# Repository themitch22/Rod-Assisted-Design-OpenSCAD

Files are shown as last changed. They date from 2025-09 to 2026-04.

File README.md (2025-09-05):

Customizable modular connector system for dowel rods, pipes, and tubes!

This OpenSCAD model was created to construct anything from readily-available and affordable materials such as wooden dowels, PVC pipe, electrical conduit, drinking straws, etc. 

I spent a lot of time developing this OpenSCAD model, if you found this useful and would like to support me, I am accepting tips Ko-Fi tips: https://ko-fi.com/mitch3d

There are 4 types of pieces that can be created:
Connector

The connector can be customized to have a central leg, you add the number of connecting legs you need, adjust the vertical and horizontal angles, and select the diameter, thickness, rib, and screw options. There are added parameters to flatten the top and bottom of the legs to make printing easier, and have a flat side to lay shelving or panels on, and teardrops are optional to further reduce overhangs to make printing easy. Included is a option to add stoppers inside the legs to prevent the rods from slipping through the center. From my testing, the flat and positive angles can all be printed without support. 

Spacer/Panel Mount:
This piece can either be used as a spacer which you can glue to a shelf or panel, or add your own connection type using a boolean geometry. The tab option you can leave blank or enable screws which adds a single centered screw which you can mount to a plywood shelf or ziptie to foamcore board. There is also a skadis option which will add a Ikea Skadis compatible hook either vertically or horizontally. This could be used to make shelves for Skadis walls, or create tape roll holders using dowels. 

Cross Connector:
For potential structure cross bracing, there is a cross connector option. Select an angle and leg length, adjust the screw parameters, This might be useful to create a side or top reinforcement to prevent sheer forces on a structure. 

End Cap/Foot:
The rough edges of a dowel or pipe might be sharp so there is an end cap option. The end cap can also be a foot if you are making shelving to prevent damage to flooring. You could customize this further to add adjustable feet or merge with other models.
Customizing with OpenSCAD

Download the latest version of OpenSCAD 

Install for your system and open the .scad file provided. By default the Customizer panel should be shown next to the preview panel. When you enter a parameter and press enter or tab, it will automatically update the preview. 

    Select the type of connector you need. The default is 1 - connector. 
    Find out your dowel or tube OD, you should get an average diameter with calipers for a tight fit but not too tight. Screws will hold the rods in place, but any play in the connection will cause stress. Add about 0.1-0.2mm of tolerance for extrusion or printer inconsistency, layer squish, or material shrinkage.
     You will need to figure out the number of legs needed and their horizontal or vertical angle. Most features only work with a 0 degree flat vertical angle, but the horizontal angle can be adjusted to suit your needs. If the horizontal angle and number of legs exceed 360 degrees, it will evenly adjust horizontal angle to fit the number of legs around the center leg. 
    Adjust the leg length, center leg length, thickness, rid reinforcement, and chamfer to desired proportions. 
    Decide if you want screws and enable them, and pick either countersink or counterbore so the screw doesn't stick out (unless desired). Then the other parameters including screw angle, which you should adjust to prevent accessibility and geometry issues with interference.
    When you are ready, press Render (F6) first. Then you can Save to STL.

Considerations

Use at your own risk!

3D printed parts, dowels, or tubing are widely variable, you should test your structures first before relying on them to hold any loads. 

Do not trust this to hold anything or anyone you care about. While I'd love to see this be used to make furniture, it should be heavily reinforced with the length of the rod in direct compression to the ground, not in direction of tensile or sheer stresses. Remember to have the sheer strength perpendicular to the layers not parallel along layers. 

PLA while rigid, can creep over time, PETG, ABS, ASA, and CF reinforced filaments are more likely to hold up over time. The material used in the pictures is ASA.

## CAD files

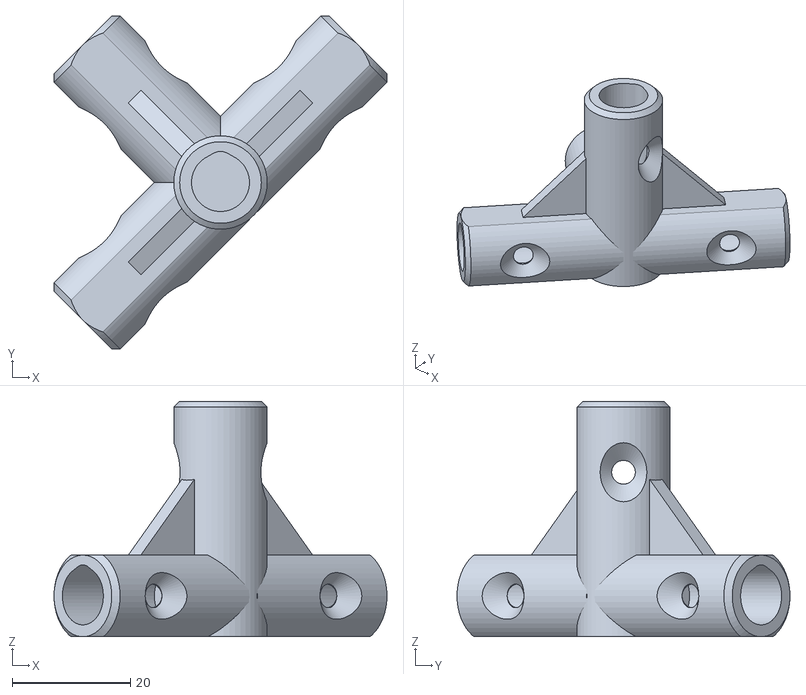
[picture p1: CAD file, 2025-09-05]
3-8th 4-way connector #8 cs screw flat 90 degree.stl
56.3 x 56.3 x 39.8

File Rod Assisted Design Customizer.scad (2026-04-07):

//Dowel Aided Design - Parametric Modular Dowel Rod/ Tube System
//by Mitch Cerroni - Mitch 3D (mitch3D.com)
//https://github.com/themitch22/Rod-Assisted-Design-OpenSCAD
//Original repository: https://www.printables.com/model/1402479/

//number of faces, optimize for rendering / 3D printing. 
$fn = 50; 

// ---------- Dowel Connector Parameters ---------------------

// 1 = dowel connector, 2 = spacer/panel mount, 3 = cross connector, 4 = endcap
type = 1;

// Diameter in mm for dowel holes, keep in mind tolerance when printing. 1in ~ 26mm, 1/2in ~ 13mm, 3/8 ~10mm, 1/4in ~6.5mm
dowelDia = 26;

// Thickness of the walls in mm, bigger number is stronger but can cause interferences.
thickness = 6;

// Chamfer length in mm, this softens edges and looks nicer.
chamfer = 3;

// Total number of side legs. If legNum and horzAngle are more than 360 degrees it will evenly distribute leg count around center leg.
legNum = 2; 

// Horizontal angle (degrees) between side legs. If total is over 360, legs are evenly spaced instead.
horzAngle = 90;

// Vertical angle (degrees) for side legs, negative values disable flat features and lowers center leg.
vertAngle = 0; 

// If this list is populated, it will override the horzAngle and populate . If it one 360 degrees it'll be ignored. example [0, 30, 180, 270]
horzAngleList = [];

// Legth in mm for the center leg, this is to compensate for the possible angles of side legs as you might want clearance to access screw holes, or have a shorter middle leg for some reason.
centerLegLength = 50;

// Length in mm, this length is additional to the leg total diameter.
lengthLeg = 50;

// If vertical angle is positive, a rib between legs and center to provide strength. 
// 0 = disabled. Rib will disable if larger than the centerLegLength or legLength (including legDia).
ribSize = 20;

// Adding internal leg stoppers to prevent dowels going too far and intersecting
// Only available for connector, not for spacer/panel mount or cross connector. 
// The geometry might have issues with certain angles.
// 0 = disabled, 1 = stoppers in leg(s) only, 2 = stoppers in leg(s) and center leg.
stopperEnable = 1;

// If vertical angle is positive, it flattens bottom for printing or shelves. 1 = True
flatBottomEnable = 1;

// Amount in mm to flatten the bottom for easier printing and/or shelving depending on orientation. 
// If using cross connector, this can be adjusted to suit your printability needs.
// Keep this under thickness value.
flatBottomDepth = 3;

// If vertical angle is 0 (flat), it flattens top of legs for shelves. 1 = True.
flatTopEnable = 1;

// Amount in mm to flatted the top of each leg for shelving. Use depending on application. 
// If spacer/panel mount is selected, it will compensate height to be co-planar to connector tops. 
// Not every connector will have this flat side depending on orientation which may cause alignment issues.
// Keep this under thickness value.
flatTopDepth = 3;

// Arched top of dowel hole to reduce overhangs. 1 = True 
teardropEnable = 1;

// ---------- Screw parameters ----------------

// Screws enabled if angle list is populated. Add angle for screws separate by comma, example: [0, 180] for top and bottom, or [90, 270] for sides, [0, 90, 180, 270} for top and sides.
// You may have some intersection issues with screw holes depending on angles.

//screwAngle = 0;
screwAngleList = [0, 180];

// Enable countersink for screws.
screwEnableCS = 1;

// Enable counterbore for screws.
screwEnableCB = 0;

// Diameter in mm for screw hole.
screwDia = 4;

// Offset in mm for screw hole from leg length inward, a higher value goes towards the center. 
screwOffset = 18; 

// Countersink and counterbore screw depth in mm for screw heads, thickness from dowel out. 
screwDepth = 0;

// Counterbore screw diameter in mm for screw heads.
screwCBDia = 9;

// --------- Spacer/Panel Mount Parameters ----------------

// For spacer/panel mounts, the lenth of the tab. 0 or skadisTab enabled diables it.
tabLength = 25;

// For spacer/panel mount, it adds a Ikea Skadis capable hook. 0 = disabled, 1 = verticle, 2 = horizontal. 
// Fixed dimensions so may cause interference issues. 
skadisTab = 0;

// ------------ Cross connector and endcap ---------------

// If selected, the angle of the crossing connectors in degrees. Cross connector uses legLengt parameter. Uses flatBottomDepth if enabled and positive for easier printing. 0 or 90 just make a single leg, with double screws, might be useful as a splice joint. 
crossAngle = 30;

// If selected, the length of the endcap piece. Used as a foot or stopper.
endcapLength = 40;

// Function to total leg diameter.
function legDia() = dowelDia+thickness*2;

// Number clamping, legLength can't be smaller than leg diameter.
legLength = lengthLeg < legDia() ? legDia() : lengthLeg; 

// Verifying legNum and horzAngle aren't over 360 degrees, this helps optimization. 
// If over 360 degree it distributes legNum evenly around the center. 
legHorzAngle = legNum * horzAngle > 360 ? 360 / legNum : horzAngle;

stopperLeg = stopperEnable > 0 ? legDia()/2 : 0;
stopperCenter = stopperEnable >= 2 ? legDia() : 0;

echo(legLength);
echo(legHorzAngle);
horzAngleListNum = len(horzAngleList);
echo(horzAngleListNum);

// Creates leg with chamfer.
module leg(length){
    cylinder(h=chamfer,d1=(legDia()-chamfer*2),d2=(legDia()));
    translate([0, 0, chamfer])
        cylinder(h=(length-chamfer*2),d=(legDia()));
    translate([0, 0, (length-chamfer)])
        cylinder(h=chamfer,d1=(legDia()),d2=(legDia()-chamfer*2));
    };    

// creates the dowel hole features and screw holes which are subtracted later.
module dowelhole(length, offsetScrew, teardrop, stopper){

    if (stopper == 0) { // if stopper is 0 it disables the feature. 
            
            if(teardrop == 1){ // If enabled, add arch to reduce overhangs in dowel hole.
                hull(){
                    translate([0,dowelDia/3.5,0]) {
                        cylinder(h=length + chamfer * 2, d = dowelDia/2);
                    }    
                    cylinder(h=length + chamfer * 2, d = dowelDia); // Center dowel hole feature
                }    
            }
            
            else cylinder(h=length + chamfer * 2, d = dowelDia); // Center dowel hole feature
    }

    if (stopper > 0) { // stopper arg is for offset distance, this allows each leg to be different if needed.
        difference() {
            
            if(teardrop == 1){ // If enabled, add arch to reduce overhangs in dowel hole.
                hull(){
                    translate([0,dowelDia/3.5,0]) {
                        cylinder(h = length + chamfer * 2, d = dowelDia/2);
                    }    
                    cylinder(h=length + chamfer * 2, d = dowelDia); // Center dowel hole feature
                }    
            }
            
            else cylinder(h=length + chamfer * 2, d = dowelDia); // Center dowel hole feature
            
            if(teardrop == 1){ // If enabled, add arch to reduce overhangs in dowel hole.
                translate([0,0,0]) {
                    hull(){
                        translate([0,dowelDia/3.5,0]) {
                            cylinder(h = stopper + thickness, d = dowelDia/2);
                        }    
                        cylinder(h = stopper + thickness, d = dowelDia); // Center dowel hole feature
                    }
                }    
            }
            
            else translate([0,0,0]) {
                    cylinder(h = stopper + thickness, d = dowelDia); // Center dowel hole feature
            }
        }
    }    
    

    
    // Screw hole if enabled
    if(len(screwAngleList) > 0){
        for(screwAngle = screwAngleList) {
        
            translate([0,0,offsetScrew]) {
                rotate([90,0,screwAngle]){
                    cylinder(h=legDia()/2, d = screwDia, center = false);
                }
            }
            
            // Screw hole countersinks on top and bottom    

            translate([(legDia()+screwDepth/2)*sin(180-screwAngle)/2,(legDia()+screwDepth/2)*cos(180-screwAngle)/2,offsetScrew]) {
                rotate([0,90,90+screwAngle]){
                    if(screwEnableCS == 1){
                        cylinder(h=thickness-screwDepth, d1 = thickness*2+screwDia, d2 = screwDia);
                    }
                    if(screwEnableCB == 1){
                        cylinder(h=thickness-screwDepth, d=screwCBDia);
                    }
                }
            }    
        }    
    }

}
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

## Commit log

2025-09-05 Add example STL created from default parameters.
    [3-8th 4-way connector #8 cs screw flat 90 degree.stl]
2025-09-05 fix weird unicode error
    [Rod Assisted Design Customizer.scad]
2025-09-05 removed line 4
    [Rod Assisted Design Customizer.scad]
2025-09-07 chamfercube and flatTopDepth fixes
    Added inline conditionals to spacer/panel mount to verify if flatTopEnable = 1 and pass flatTopDepth
    Fixed chamfercube, cubechamfer to be chamfer * squrt(2) which is more accurate to the diagonal of a chamfer (Pythagorean theorem)
    [Rod Assisted Design Customizer.scad]
2025-09-07 Add files via upload
    Added horzAngleList parameter and conditional if the list is populated with angles, it creates that number of legs with corresponding angles. It will not validate the angles in the list, I will add s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
    [Rod Assisted Design Customizer.scad]
2026-04-07 Updated screw holes with screwAngleList functions
    Thanks for the suggestion from naomilynda on Printables to customize screw angles. This reduced some redundancy I had in the screw hole features, It allows a custom list of screw angles and enable sc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
    [Rod Assisted Design Customizer.scad]
